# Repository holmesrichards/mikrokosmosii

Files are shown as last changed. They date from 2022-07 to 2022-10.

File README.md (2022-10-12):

# Mikrokosmos II

This is a synth module in Kosmo format, inspired by Music Thing Modular's [Mikrophonie](https://www.musicthing.co.uk/Mikrophonie/). Like that module, Mikrokosmos II has a piezo pickup attached behind the front panel, and the circuit amplifies the piezo signal and sends it to the output. There is a tactile scratch area on the front panel. You can use your fingernail or a guitar pick to scrape across it and generate output. It will also pick up sounds when you tap or thump on the synth case, plug or unplug cables, and so on. People have attached springs to the front panel, even a coil spring type doorstop. There are lots of possibilities.

There also is a jack for plugging in an external piezo pickup attached to a cable.

The first version of Mikrokosmos was a Kosmo conversion of the Mikrophonie circuit. Mikrokosmos II replaces that circuit with one based on a [design](https://www.logosfoundation.org/g_texts/Orfeus/preamps/piezo_disks.html) by composer, performer, and instrument maker Godfried-Willem Raes. This preamp is designed specifically for piezo pickups and gives better frequency response than a typical constant impedance amplifier.

## About the name

Mikrophonie's name comes from that of a [composition](https://en.wikipedia.org/wiki/Mikrophonie_(Stockhausen)) by Karlheinz Stockhausen. "Mikrokosmos" is an obvious portmanteau of "Mikrophonie" and "Kosmo", and pays homage to a [collection of piano pieces](https://en.wikipedia.org/wiki/Mikrokosmos_(Bart%C3%B3k)) with that name by Béla Bartók. Apparently it also is the name of a song by BTS, but that has nothing to do with this module.

## Current draw
? mA +12 V, ? mA -12 V

## Photos

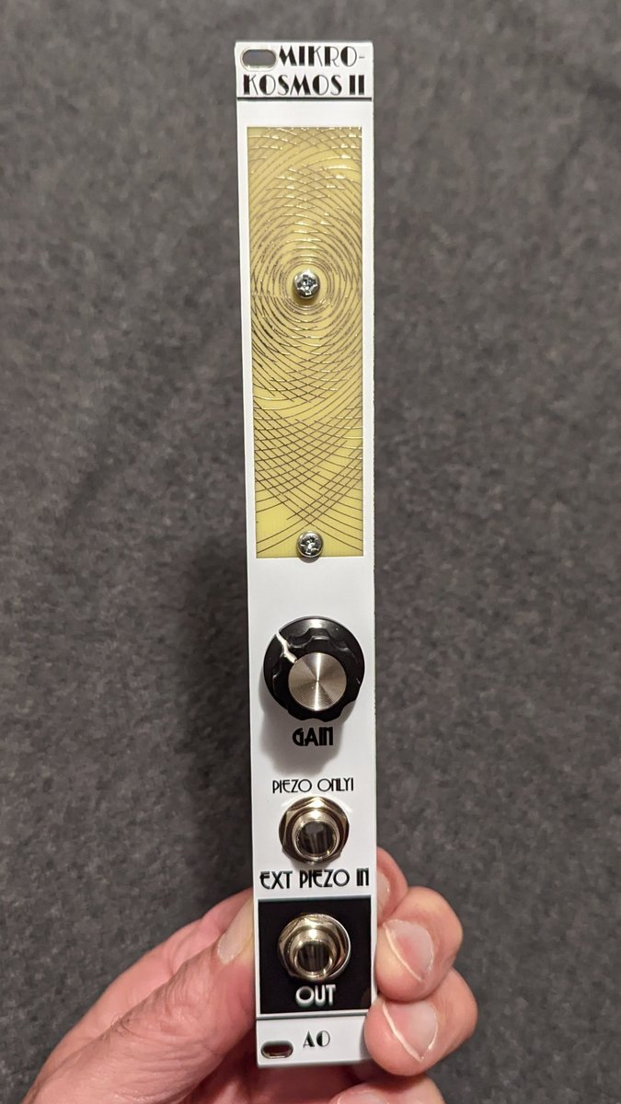
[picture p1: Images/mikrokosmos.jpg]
mikrokosmos


## Documentation

* [Schematic](Docs/mikrokosmos-ii.pdf)
* PCB layout: [front](Docs/mikrokosmos-ii_layout_front.pdf), [back](Docs/mikrokosmos-ii_layout_back.pdf)
* [BOM](Docs/mikrokosmos-ii_bom.md)
* [Build notes](Docs/build.md)

## GitHub repository

* [https://github.com/holmesrichards/mikrokosmosii](https://github.com/holmesrichards/mikrokosmosii)

## Submodules

This repo uses submodules aoKicad and Kosmo_panel, which provide needed libaries for KiCad. To clone:

```
git clone git@github.com:holmesrichards/microkosmos-ii.git
git submodule init
git submodule update
```

Alternatively do

```
git clone --recurse-submodules git@github.com:holmesrichards/microkosmos-ii.git
```

Or if you download the repository as a zip file, you must also click on the "aoKicad" and "Kosmo\_panel" links on the GitHub page (they'll have "@ something" after them) and download them as separate zip files which you can unzip into this repo's aoKicad and Kosmo\_panel directories.

If desired, copy the files from aoKicad and Kosmo\_panel to wherever you prefer (your KiCad user library directory, for instance, if you have one). Then in KiCad, go into Edit Symbols and add symbol libraries 

```
aoKicad/ao_symbols
Kosmo_panel/Kosmo
```
and go into Edit Footprints and add footprint libraries 
```
aoKicad/ao_tht
Kosmo_panel/Kosmo_panel.
```

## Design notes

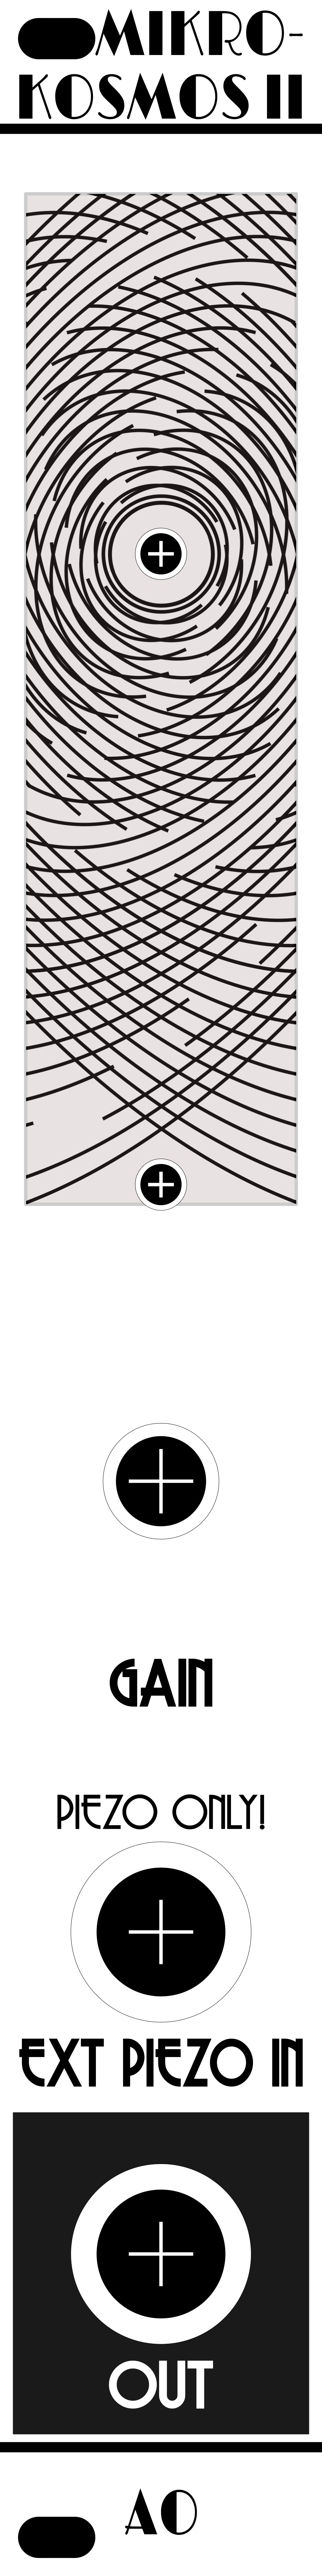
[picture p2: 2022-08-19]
Images/mikrokosmos-ii_panel_holes.png

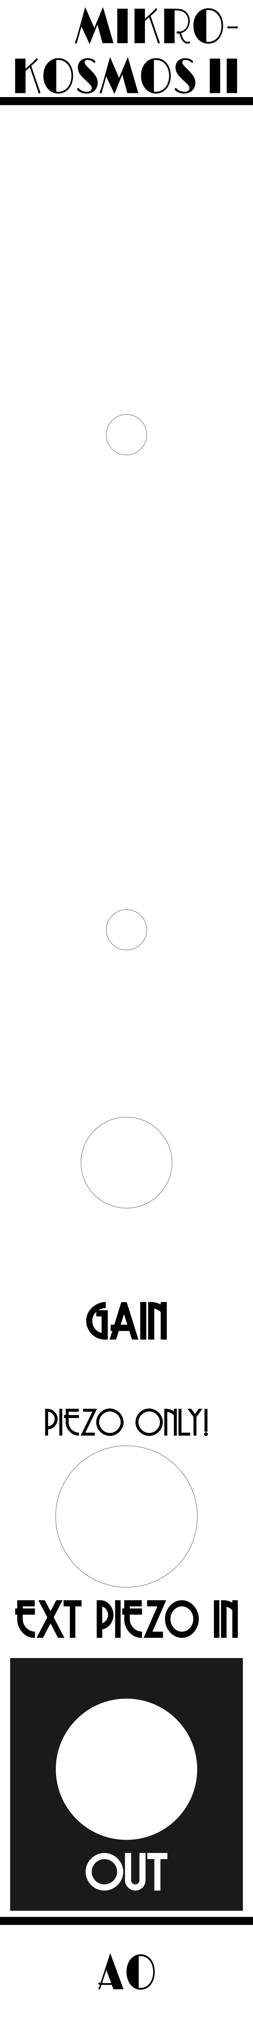
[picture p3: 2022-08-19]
Images/mikrokosmos-ii_panel_art.png

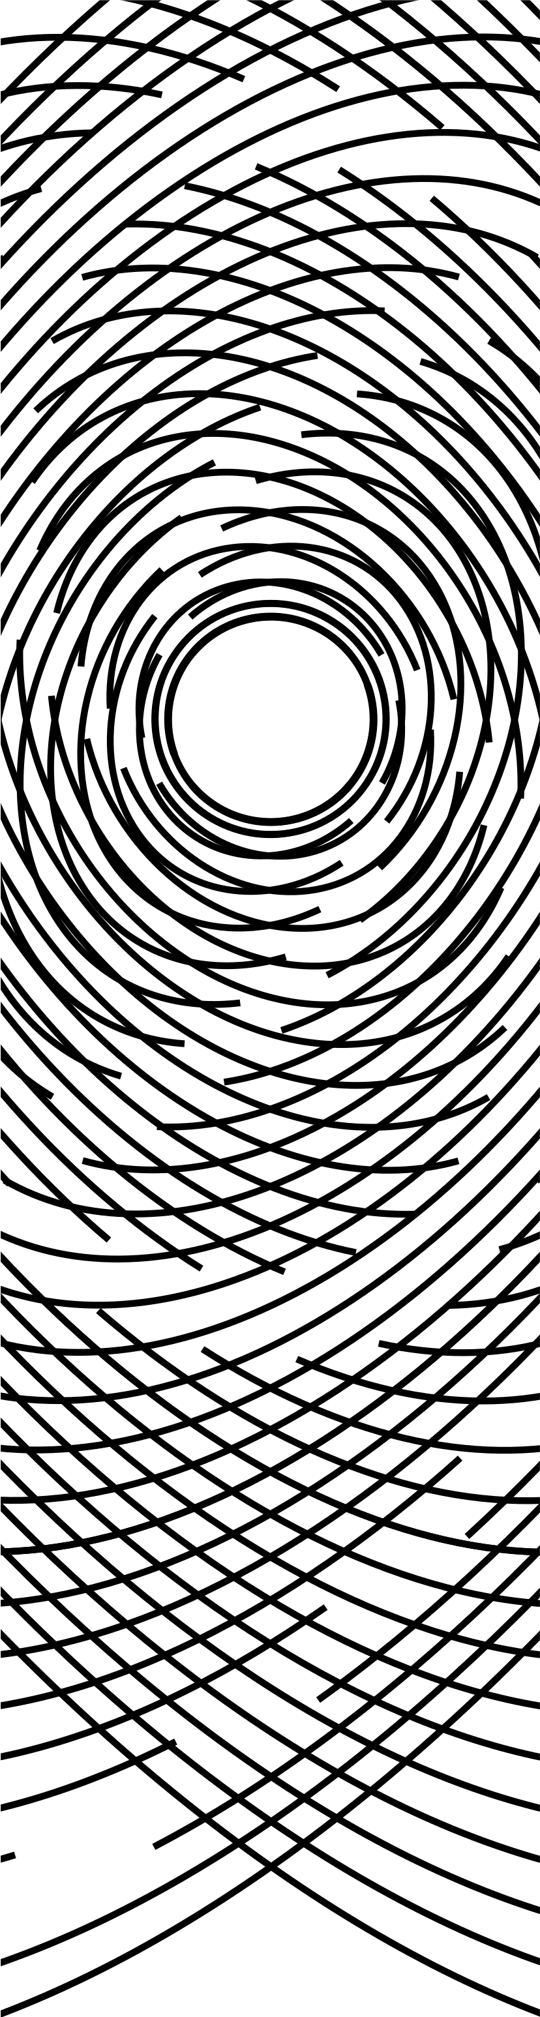
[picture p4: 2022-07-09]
Images/artc.png

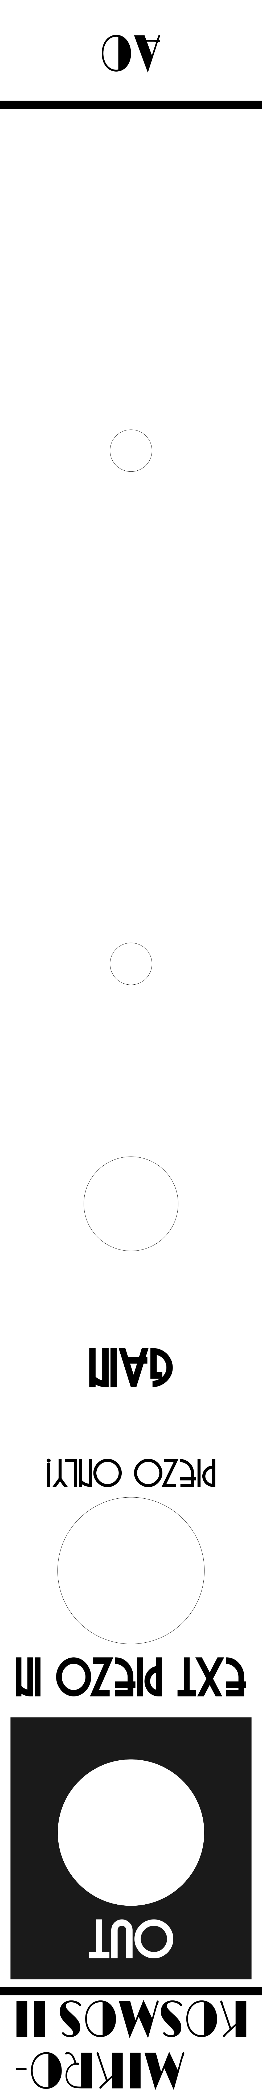
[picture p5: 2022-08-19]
Images/mikrokosmos-ii_panel_inv_art.png

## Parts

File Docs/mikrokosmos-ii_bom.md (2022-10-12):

# mikrokosmos-ii.kicad_sch BOM

Thu 22 Sep 2022 09:02:36 PM EDT

Generated from schematic by Eeschema 6.0.7-f9a2dced07~116~ubuntu22.04.1

**Component Count:** 31

| Refs | Qty | Component | Description | Vendor | SKU |
| ----- | --- | ---- | --- | ---- | ---- |
| C1, C2 | 2 | 10uF | Electrolytic capacitor | Tayda |  |
| C3 | 1 | 1nF | Film capacitor |  |  |
| C4, C5 | 2 | 100nF | Ceramic capacitor |  |  |
| C6, C7 | 2 | 47nF | Film capacitor |  |  |
| C8 | 1 | 330pF | Ceramic capacitor |  |  |
| C9 | 1 | 2.2uF | Non polarized electrolytic capacitor | Tayda |  |
| D1, D2, D3, D4 | 4 | 1N5817 | Schottky diode |  |  |
| J1 | 1 | AudioJack2_SwitchT | Audio Jack, 2 Poles (Mono / TS), Switched T Pole (Normalling) | Tayda | A-1121 |
| J2 | 1 | Synth_power_2x5 | Pin header 2.54 mm 2x5 | Tayda | A-2939 |
| J3, J5 | 2 | 2_pin_Molex_connector | KK254 Molex connector | Tayda | A-826 |
| J4, J6 | 2 | 2_pin_Molex_header | KK254 Molex header | Tayda | A-804 |
| J7 | 1 | AudioJack2 | Audio Jack, 2 Poles (Mono / TS) | Tayda | A-1121 |
| LS1 | 1 | Piezo |  |  |  |
| R1, R4 | 2 | 1M | Resistor | Tayda |  |
| R2 | 1 | 10M | Resistor | Tayda |  |
| R3, R8 | 2 | 1k | Resistor | Tayda |  |
| R5 | 1 | 2k | Resistor | Tayda |  |
| R6 | 1 | 100k | Resistor | Tayda |  |
| R7 | 1 | 4.7k | Resistor | Tayda |  |
| RV1 | 1 | A5k | Potentiometer | Tayda |  |
| U1 | 1 | TL072 | Dual Low-Noise JFET-Input Operational Amplifiers, DIP-8/SOIC-8 | Tayda |  |
| | 1 | | Knob | | | | |
| | 1 | | 8 pin DIP socket | | | Tayda | A-001 |
| | 4 | | M3x6 screw | | | | |
| | 2 | | 10 mm spacer | | | Tayda | A-1235 |

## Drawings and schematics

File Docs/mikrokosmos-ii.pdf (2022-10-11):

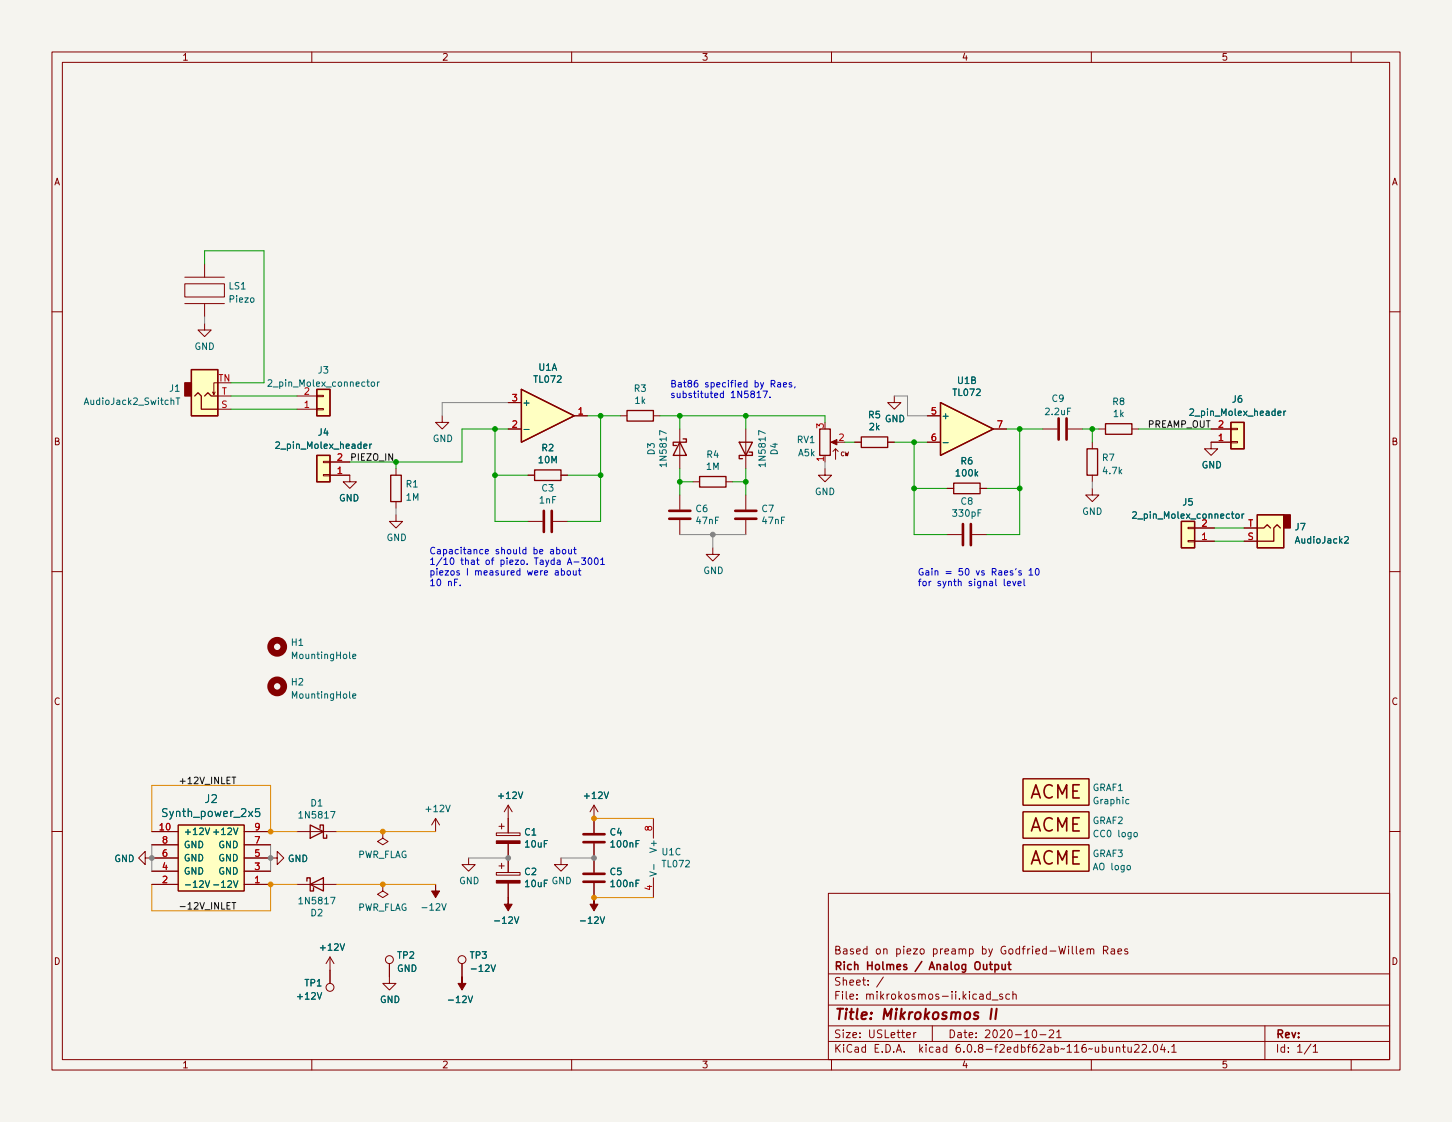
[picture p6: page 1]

Capacitance should be about
1/10 that of piezo. Tayda A-3001

for synth signal level

Based on piezo preamp by Godfried-Willem Raes
File: mikrokosmos-ii.kicad_sch Sheet: / Rich Holmes / Analog Output

Id: 1/1 Title: Mikrokosmos II

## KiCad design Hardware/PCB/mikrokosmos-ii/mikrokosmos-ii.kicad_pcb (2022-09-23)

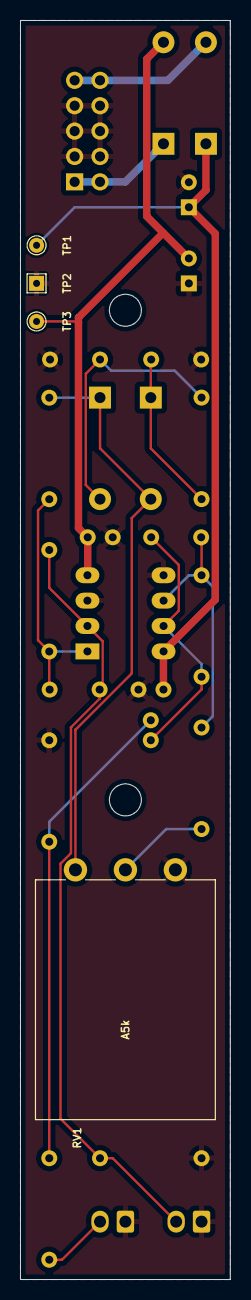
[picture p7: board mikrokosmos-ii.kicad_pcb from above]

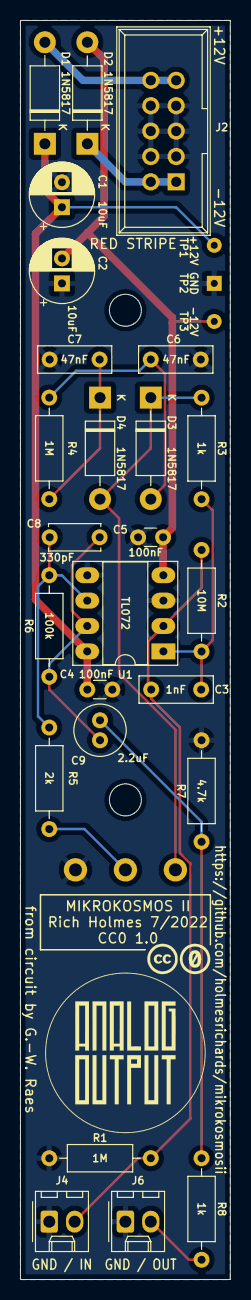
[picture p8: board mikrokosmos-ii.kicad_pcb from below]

Board: 2 copper layers, 21.0 x 126.0 mm, 34 parts (27 on the bottom side), 15 nets.

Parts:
C1, C2: 10uF; CP_Radial_D6.3mm_P2.50mm
C3: 1nF; C_Rect_L7.2mm_W2.5mm_P5.00mm_FKS2_FKP2_MKS2_MKP2
C4, C5: 100nF; C_Disc_D3.0mm_W1.6mm_P2.50mm
C6, C7: 47nF; C_Rect_L7.2mm_W2.5mm_P5.00mm_FKS2_FKP2_MKS2_MKP2
C8: 330pF; C_Disc_D5.0mm_W2.5mm_P5.00mm
C9: 2.2uF; C_Radial_D5.0mm_H11.0mm_P2.00mm
D1, D2, D3, D4: 1N5817; D_DO-41_SOD81_P10.16mm_Horizontal
GRAF1: Graphic; mikrokosmos-ii_panel_holes
GRAF2: CC0 logo; CC0_logo
GRAF3: AO logo; analogoutput
H1, H2: MountingHole; MountingHole_3.2mm_M3
J2: Synth_power_2x5; Power_Header
J4, J6: 2_pin_Molex_header; Molex_KK-254_AE-6410-02A_1x02_P2.54mm_Vertical
R1, R4: 1M; R_Axial_DIN0207_L6.3mm_D2.5mm_P10.16mm_Horizontal
R2: 10M; R_Axial_DIN0207_L6.3mm_D2.5mm_P10.16mm_Horizontal
R3, R8: 1k; R_Axial_DIN0207_L6.3mm_D2.5mm_P10.16mm_Horizontal
R5: 2k; R_Axial_DIN0207_L6.3mm_D2.5mm_P10.16mm_Horizontal
R6: 100k; R_Axial_DIN0207_L6.3mm_D2.5mm_P10.16mm_Horizontal
R7: 4.7k; R_Axial_DIN0207_L6.3mm_D2.5mm_P10.16mm_Horizontal
RV1: A5k; Potentiometer_Alpha_16mm_Single_Vertical
TP1: +12V; TestPoint_THTPad_D1.5mm_Drill0.7mm
TP2: GND; TestPoint_THTPad_1.5x1.5mm_Drill0.7mm
TP3: -12V; TestPoint_THTPad_D1.5mm_Drill0.7mm
U1: TL072; DIP-8_W7.62mm_Socket_LongPads

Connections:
+12V: C1.1, C4.1, D1.1 (K), TP1.1, U1.8 (V+)
-12V: C2.2, C5.2, D2.2 (A), TP3.1, U1.4 (V-)
/+12V_INLET: D1.2 (A), J2.9 (+12V), J2.10 (+12V)
/-12V_INLET: D2.1 (K), J2.1 (-12V), J2.2 (-12V)
/PIEZO_IN: C3.2, J4.2, R1.1, R2.2, U1.2 (-)
/PREAMP_OUT: J6.2, R8.1
GND: C1.2, C2.1, C4.2, C5.1, C6.2, C7.2, J2.3 (GND), J2.4 (GND), J2.5 (GND), J2.6 (GND), J2.7 (GND), J2.8 (GND), J4.1, J6.1, R1.2, R7.2, RV1.1, TP2.1, U1.3 (+), U1.5 (+)
unnamed: C3.1, R2.1, R3.2, U1.1
unnamed: C6.1, D3.2 (A), R4.2
unnamed: C7.1, D4.1 (K), R4.1
unnamed: C8.1, C9.1, R6.1, U1.7
unnamed: C8.2, R5.1, R6.2, U1.6 (-)
unnamed: C9.2, R7.1, R8.2
unnamed: D3.1 (K), D4.2 (A), R3.1, RV1.3
unnamed: R5.2, RV1.2

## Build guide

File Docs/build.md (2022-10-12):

# Microkosmos II build notes

This is a very simple and straightforward build. Just a few special things to note:

Capacitor C3's value should be about 1/10 of the piezo capacitance. I measured the disks I got from Tayda at about 10 nF, so used 1 nF for C3.

The panel is double sided. One side allows mounting the module with the scratch area at the top and the jacks at the bottom. The other side allows vice versa. You might prefer the latter if you are mounting it down low with the patch cords heading upwards.

The piezo element should be attached to the back of the front panel, in the scratch area. I have used double stick adhesive strips successfully; hot glue may also work. *Check the panel orientation before attaching the piezo!* Then connect the black wire to the ground terminal of the input jack and the red wire to the tip switch terminal of the input jack. You may need to add extensions to these wires to get them to reach.

Before soldering the pot, attach it to the front panel loosely. Put the PCB onto the pot pins and attach it to the front panel with two 10 mm M3 spacers using four 6 mm M3 screws. Then solder the pot.

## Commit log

2022-06-10 Initial version
    [mikrokosmos-ii.kicad_pcb, mikrokosmos-ii.kicad_sch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]
2022-06-11 README, reorient capacitor
    [mikrokosmos-ii.kicad_pcb]
2022-06-20 Small refinements to layout and schem
    [mikrokosmos-ii.kicad_pcb, mikrokosmos-ii.kicad_sch]
2022-07-09 PCB touchup, reorg files, panel
    [mikrokosmos-ii-panel.kicad_pcb, mikrokosmos-ii-panel.kicad_sch, mikrokosmos-ii.kicad_pcb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]
2022-08-19 panel, PCB updates
    [mikrokosmos-ii-panel.kicad_pcb, mikrokosmos-ii-panel.kicad_sch, mikrokosmos-ii.kicad_pcb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]
2022-09-23 Pre fab tweaks, Gerbers, cap descriptions
    [mikrokosmos-ii-CmtUser.gbr, mikrokosmos-ii-CuBottom.gbl, mikrokosmos-ii-CuTop.gtl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]
2022-10-12 build notes and BOM update
2022-10-12 build notes and BOM correction
